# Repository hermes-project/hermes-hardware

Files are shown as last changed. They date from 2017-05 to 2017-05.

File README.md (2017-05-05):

# hermes-hardware
# Authors : François Charles, Simon Ménard, Raphaël Outhier

This repository lists all you need if you're interested in the robot hardware's architecture.

What you may find in this repository :

-the 3D models designed with SolidWorks CAD;

-the Eagle CAD PCB schematics and board layout

-the Eagle CAD libraries used

-the datasheets of electronic components

-documentation about how to drive the robot successfully (in French at the moment :p English version to come)

Enjoy your trip among these files ! :)

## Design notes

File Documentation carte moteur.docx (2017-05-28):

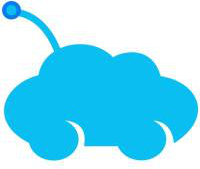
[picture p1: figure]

# Hermès ϕ – Documentation carte moteur

Auteur : François Charles-Orszag

Ce document résume les composants de la carte et ses fonctionnalités en accord avec les datasheets fournies par les constructeurs. Vous pouvez vous référer aux dites datasheets sur le site du projet Hermès, ou accéder aux liens listés dans la section Références.

## Description générale

Cette carte permet de commander un moteur à courant continu. Elle est principalement constituée de deux circuits intégrés, basés sur une structure électronique interne de pont en H. Le moteur possède trois entrées pour commander la rotation horaire, antihoraire et le freinage. Ces signaux sont compatibles avec les niveaux logiques TTL. Les différents blocs présents sur la carte sont détaillés dans la Figure 1 accompagnée de sa légende en Figure 2.

Alimentation +5V et signaux de commandes moteur

Alimentation et signaux codeur optique

Alimentation +24 V de la carte

Alimentation des moteurs

Drivers de puissance

Figure 2 : Détail des blocs

Figure 1 : Emplacement des blocs

La carte est accompagnée d’une sérigraphie (texte en blanc par-dessus le vernis vert) pour fournir une indication visuelle rapide sur les fonctions des différents contacts électriques. Ils sont détaillés dans la partie suivante Pinout et fonctionnalités.

## Pinout et fonctionnalités

Dans un premier temps, cette partie expose sous forme de tableaux les conventions utilisées pour le câblage des connecteurs. Elle montre dans un second temps comment utiliser les signaux de commande du moteur pour le contrôler. Les connectiques utilisées sont répertoriées dans la section Références, Tableau 1.

N.B. : Comprendre le mot « pin » comme une patte d’un composant, mot récurrent dans la documentation anglaise. Les secondes dénominations de la colonne fonction, comme « Vcc1 » ou « IN1 », sont liées aux notations des datasheets respectives des composants.

Connecteur d’alimentation

Numéro du pin - Couleur de câble | Fonction
1 – Rouge | +24 V / Vcc 1
2 – Noir | Masse / GND

Connecteur de moteur

Numéro du pin - Couleur de câble | Fonction
1 - Noir | Output 2
2 - Rouge | Output 1

Connecteur de codeur optique

Numéro du pin - Couleur de câble | Fonction
1 - Violet | Canal B / Hall sensor B Vout
2 - Bleu | Canal A / Hall sensor A Vout
3 - Vert | Masse / Hall sensor GND
4 - Marron | +5 V / Hall sensor Vcc

Connecteur à nappe

Numéro du pin - Couleur de câble | Fonction
1 – Marron | +5 V / Vcc 2
2 – Rouge | +5 V / Vcc 2
3 – Orange | Input 2 / IN2
4 – Jaune | Input d’activation / INH
5 – Bleu | Contrôle de courant / Sense
6 – Vert | Input 1 / IN1
7 – Violet | Masse / GND
8 – Gris | Masse / GND
9 – Blanc | Codeuse canal A / Hall sensor A Vout
10 – Noir | Codeuse canal B / Hall sensor B Vout

Commandes du moteur

Action | IN1 | IN2 | INH | Remarques
Stop 1 | H | H | H ou L | | Moteur au repos
Stop 2 | H | H | H | | Moteur en mouvement
| H | L | H
| L | H | H
Rotation horaire | H | L | L
Rotation antihoraire | L | H | L
Freinage | L | L | H ou L

H : Etat logique haut (+5V / Vcc 2) L : Etat logique bas (Masse / GND)

Chronogramme d’exemple

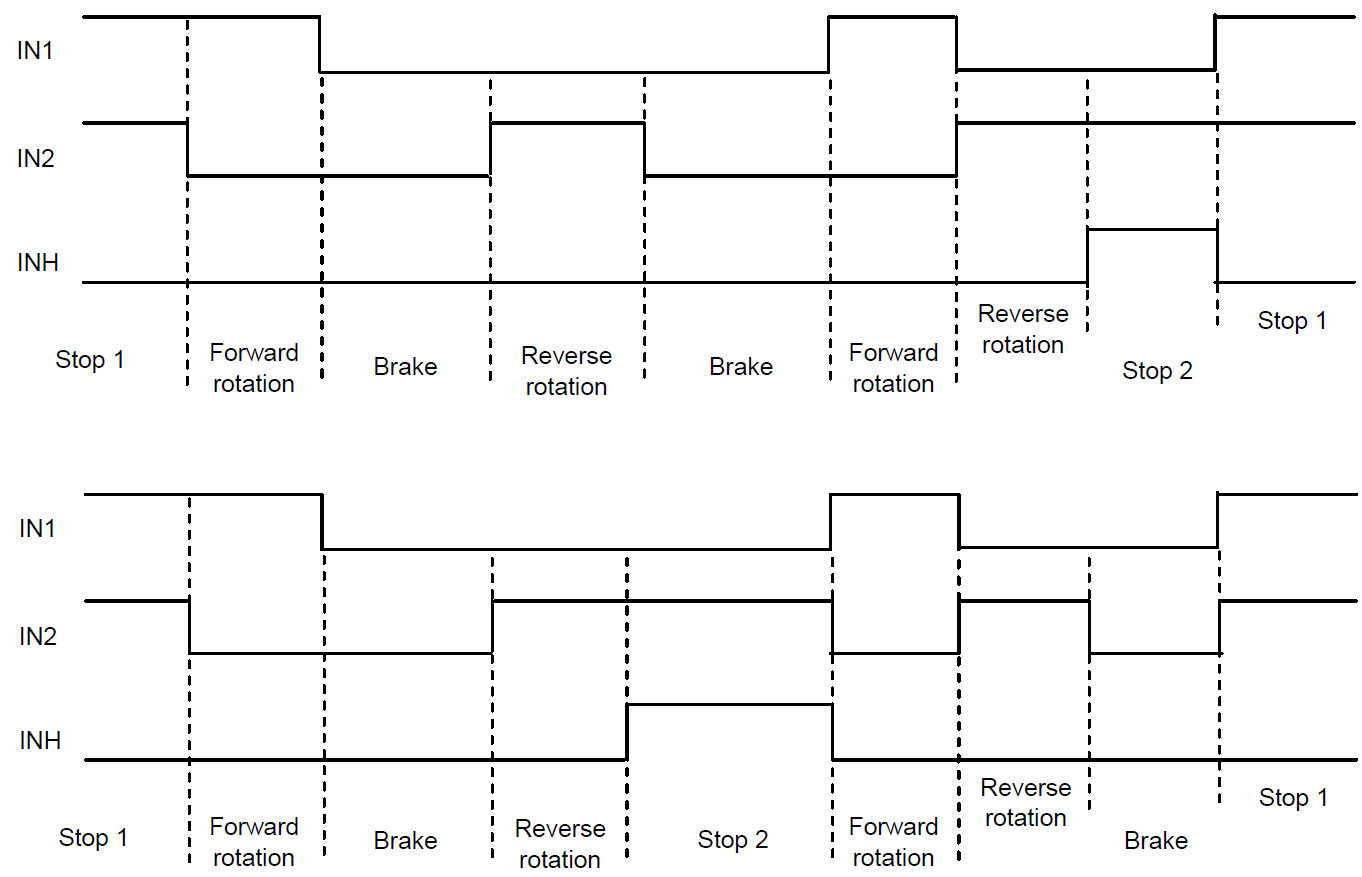
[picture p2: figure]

N.B. : La configuration IN1 = IN 2 = H et INH = L est fortement déconseillée pendant la rotation du moteur !

## Performances

Lorem ipsum.

## Précautions d’emploi et de modifications

Nous attirons l’attention de l’utilisateur dans cette partie sur les manipulations comportant des risques, aussi bien pour l’humain que pour les composants électroniques :

- Le respect des conventions de câblage est essentiel au bon fonctionnement de la carte (notamment pour le branchement de l’alimentation) car les connecteurs choisis possèdent des détrompeurs mécaniques empêchant toute erreur de polarité. Faîtes extrêmement attention si vous souhaitez changer les conventions ci-dessus, le risque étant la dégradation la carte, voire sa destruction en cas de mauvaise polarité ;
- Lors de son fonctionnement, éviter de toucher les composants de la carte, leurs boîtiers ou leurs pattes. Comme la carte fonctionne sous des courants importants quand branchés aux motoréducteurs, les composants peuvent chauffer et vous brûler. De plus, vous seriez exposé(e)s à des tensions continues d’une vingtaine de volts, issues de deux batteries au plomb. Pour éviter ces risques, la carte moteur est censée rester confinée dans son caisson de protection en utilisation ;
- En cas de dysfonctionnement, deux problèmes peuvent en être la cause. Soit les commandes des moteurs sont erronées, soit la carte ou le moteur sont endommagés. Dans le premier cas, revoyez la séquence d’ordre envoyée à la carte et vérifiez la fiabilité de l’alimentation. Dans le second cas, demandez à une personne habilitée de faire le diagnostic de la carte et de ses composants, ainsi que celui du moteur. N’essayez pas de réparer la carte si vous n’êtes pas expérimenté(e) (taper sur la carte ne la répare pas, bien que ce soit tentant) ;
- Enfin si vous voulez modifier la carte ou un de ses composants, changer la convention de câblage ou les connectiques, vous êtes priés de fournir une documentation pertinente, la présente documentation devant de facto caduque. Assurez-vous que les modifications soient adaptées à l’utilisation que vous faîtes du mobile.

## Références

Cette partie liste les liens vers les composants utilisés avec cette carte. Le tableau met en correspondance les connectiques et leurs références pour plus de clarté. En suivant ces liens, vous accéderez au site de RadioSpares, distributeur de composants électroniques.

Dénomination | Références
Alimentation | Boîtier connecteur de Molex, série SABRE (http://docs-europe.electrocomponents.com/webdocs/13c3/0900766b813c3cc1.pdf) Embase pour Circuit Imprimé de Molex, série SABRE (http://docs-europe.electrocomponents.com/webdocs/13c3/0900766b813c3b29.pdf)
Moteur | Boîtier connecteur de TE Connectivity, série MATE-N-LOK (http://docs-europe.electrocomponents.com/webdocs/03f5/0900766b803f5b91.pdf) Embase pour Circuit Imprimé de TE Connectivity, série MATE-N-LOK (http://docs-europe.electrocomponents.com/webdocs/0f93/0900766b80f93bc0.pdf)
Codeur optique | Embase pour circuit imprimé de JST, série PH (http://fr.rs-online.com/web/p/embases-de-circuit-imprime/8201434/)
Nappe | Embase pour circuit imprimé de 3M, série 303 (http://fr.rs-online.com/web/p/embases-de-circuit-imprime/8280364/) Connecteur IDC d’Amphénol, série T812 (http://fr.rs-online.com/web/p/connecteurs-idc/8323617/)

Tableau 1 : Références des connectiques

Les deux liens suivant mènent respectivement au motoréducteur et à son driver de puissance :

Motoréducteur EMG 49 de robot-electronics (http://www.robot-electronics.co.uk/htm/emg49.htm)

Driver STK681-320 de On-Semiconductor (https://www.onsemi.com/pub/Collateral/ENA0762-D.PDF)

03/05/17Documentation Carte Moteur – Hermès ϕ 2

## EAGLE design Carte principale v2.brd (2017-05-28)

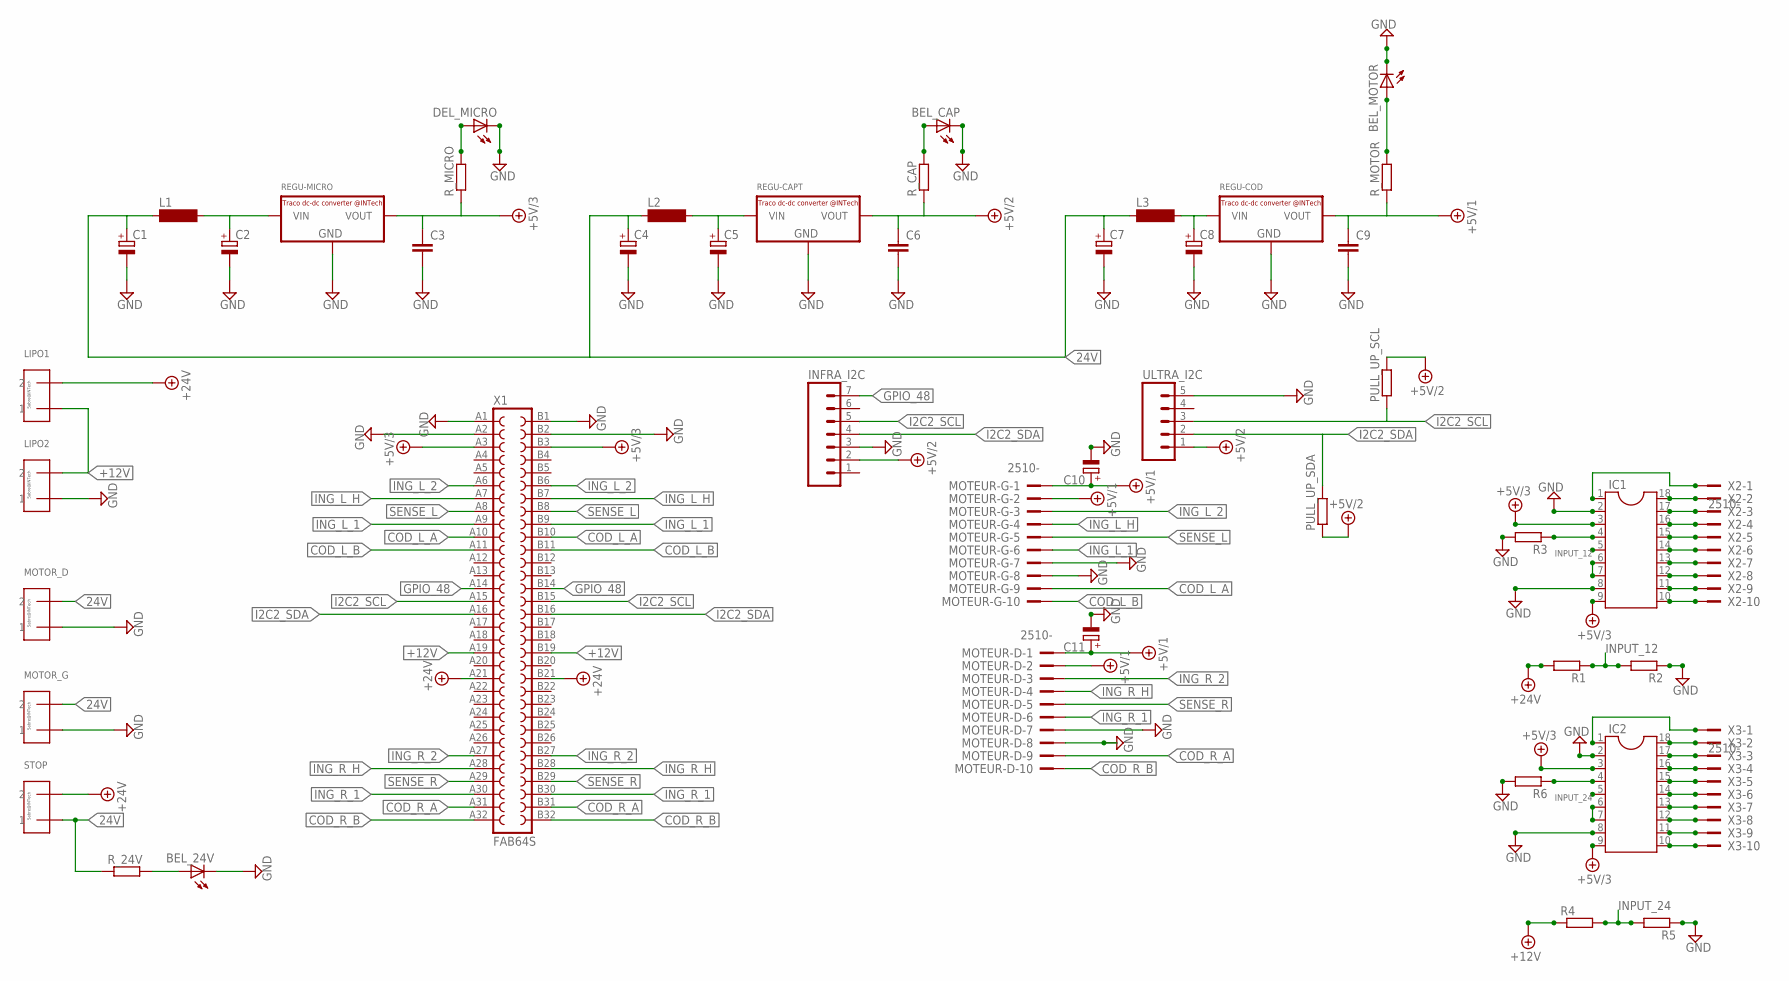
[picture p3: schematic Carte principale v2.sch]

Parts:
BEL_24V: LED5MM
BEL_CAP: LED5MM
BEL_MOTOR: LED5MM
C1, C2, C4, C5, C7, C8, C10, C11: CPOL-EUE2.5-6; E2,5-6
C3, C6: C-EU050-025X075; C050-025X075
C9: C5/3; C5B3
DEL_MICRO: LED5MM
IC1, IC2: DIL18S; SOCKET-18
INFRA_I2C: M07; 07P
L1, L2, L3: SD12-1000; SD12_1000
LIPO1, LIPO2: 43160
MOTEUR-D: 2510-; PAK100/2500-10
MOTEUR-G: 2510-; PAK100/2500-10
MOTOR_D: 43160
MOTOR_G: 43160
PULL_UP_SCL: R-EU_0204/7; 0204/7
PULL_UP_SDA: R-EU_0204/7; 0204/7
R1, R2, R3, R4, R5, R6: R-EU_0204/7; 0204/7
REGU-CAPT: R-78C-1.0_INTECH; SIP3_INTECH
REGU-COD: R-78C-1.0_INTECH; SIP3_INTECH
REGU-MICRO: R-78C-1.0_INTECH; SIP3_INTECH
R_24V: R-EU_0204/7; 0204/7
R_CAP: R-EU_0204/7; 0204/7
R_MICRO: R-EU_0204/7; 0204/7
R_MOTOR: R-EU_0204/7; 0204/7
STOP: 43160
ULTRA_I2C: M05; 05P
X1: FAB64S
X2, X3: 2510-; PAK100/2500-10

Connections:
24V: C1.+, C4.+, C7.+, L1.1, L2.1, L3.1, MOTOR_D.2_1 (2), MOTOR_D.2_2 (2), MOTOR_G.2_1 (2), MOTOR_G.2_2 (2), R_24V.1, STOP.1_1 (1), STOP.1_2 (1)
+5V/1: C9.1, C10.+, C11.+, MOTEUR-D.1, MOTEUR-D.2, MOTEUR-G.1, MOTEUR-G.2, REGU-COD.VOUT, R_MOTOR.1
+5V/2: C6.1, INFRA_I2C.2, PULL_UP_SCL.2, PULL_UP_SDA.1, REGU-CAPT.VOUT, R_CAP.1, ULTRA_I2C.1
+5V/3: C3.1, IC1.3, IC1.9, IC2.3, IC2.9, REGU-MICRO.VOUT, R_MICRO.1, X1.A3, X1.B3
+12V: LIPO1.1_1 (1), LIPO1.1_2 (1), LIPO2.2_1 (2), LIPO2.2_2 (2), R4.1, X1.A19, X1.B19
+24V: LIPO1.2_1 (2), LIPO1.2_2 (2), R1.2, STOP.2_1 (2), STOP.2_2 (2), X1.A21, X1.B21
COD_L_A: MOTEUR-G.9, X1.A10, X1.B10
COD_L_B: MOTEUR-G.10, X1.A11, X1.B11
COD_R_A: MOTEUR-D.9, X1.A31, X1.B31
COD_R_B: MOTEUR-D.10, X1.A32, X1.B32
GND: BEL_24V.K (C), BEL_CAP.K (C), BEL_MOTOR.K (C), C1.-, C2.-, C3.2, C4.-, C5.-, C6.2, C7.-, C8.-, C9.2, C10.-, C11.-, DEL_MICRO.K (C), IC1.2, IC1.8, IC2.2, IC2.8, INFRA_I2C.3, LIPO2.1_1 (1), LIPO2.1_2 (1), MOTEUR-D.7, MOTEUR-D.8, MOTEUR-G.7, MOTEUR-G.8, MOTOR_D.1_1 (1), MOTOR_D.1_2 (1), MOTOR_G.1_1 (1), MOTOR_G.1_2 (1), R2.1, R3.2, R5.1, R6.2, REGU-CAPT.GND, REGU-COD.GND, REGU-MICRO.GND, ULTRA_I2C.5, X1.A1, X1.A2, X1.B1, X1.B2
GPIO_48: INFRA_I2C.7, X1.A14, X1.B14
I2C2_SCL: INFRA_I2C.5, PULL_UP_SCL.1, ULTRA_I2C.3, X1.A15, X1.B15
I2C2_SDA: INFRA_I2C.4, PULL_UP_SDA.2, ULTRA_I2C.2, X1.A16, X1.B16
ING_L_1: MOTEUR-G.6, X1.A9, X1.B9
ING_L_2: MOTEUR-G.3, X1.A6, X1.B6
ING_L_H: MOTEUR-G.4, X1.A7, X1.B7
ING_R_1: MOTEUR-D.6, X1.A30, X1.B30
ING_R_2: MOTEUR-D.3, X1.A27, X1.B27
ING_R_H: MOTEUR-D.4, X1.A28, X1.B28
INPUT_12: IC1.5, R1.1, R2.2
INPUT_24: IC2.5, R4.2, R5.2
unnamed: DEL_MICRO.A, R_MICRO.2
unnamed: BEL_24V.A, R_24V.2
unnamed: C8.+, L3.2, REGU-COD.VIN
unnamed: C2.+, L1.2, REGU-MICRO.VIN
unnamed: C5.+, L2.2, REGU-CAPT.VIN
unnamed: BEL_CAP.A, R_CAP.2
unnamed: IC1.6, IC1.7
unnamed: IC1.12, X2.8
unnamed: IC1.13, X2.7
unnamed: BEL_MOTOR.A, R_MOTOR.2
unnamed: IC1.17, X2.3
unnamed: IC1.15, X2.5
unnamed: IC1.14, X2.6
unnamed: IC1.11, X2.9
unnamed: IC1.10, X2.10
unnamed: IC1.16, X2.4
unnamed: IC2.6, IC2.7
unnamed: IC1.18, X2.2
unnamed: IC1.1, X2.1
unnamed: IC2.10, X3.10
unnamed: IC2.11, X3.9
unnamed: IC2.12, X3.8
unnamed: IC2.13, X3.7
unnamed: IC2.14, X3.6
unnamed: IC2.15, X3.5
unnamed: IC2.16, X3.4
unnamed: IC2.17, X3.3
unnamed: IC2.18, X3.2
unnamed: IC2.1, X3.1
unnamed: IC1.4, R3.1
unnamed: IC2.4, R6.1
SENSE_L: MOTEUR-G.5, X1.A8, X1.B8
SENSE_R: MOTEUR-D.5, X1.A29, X1.B29

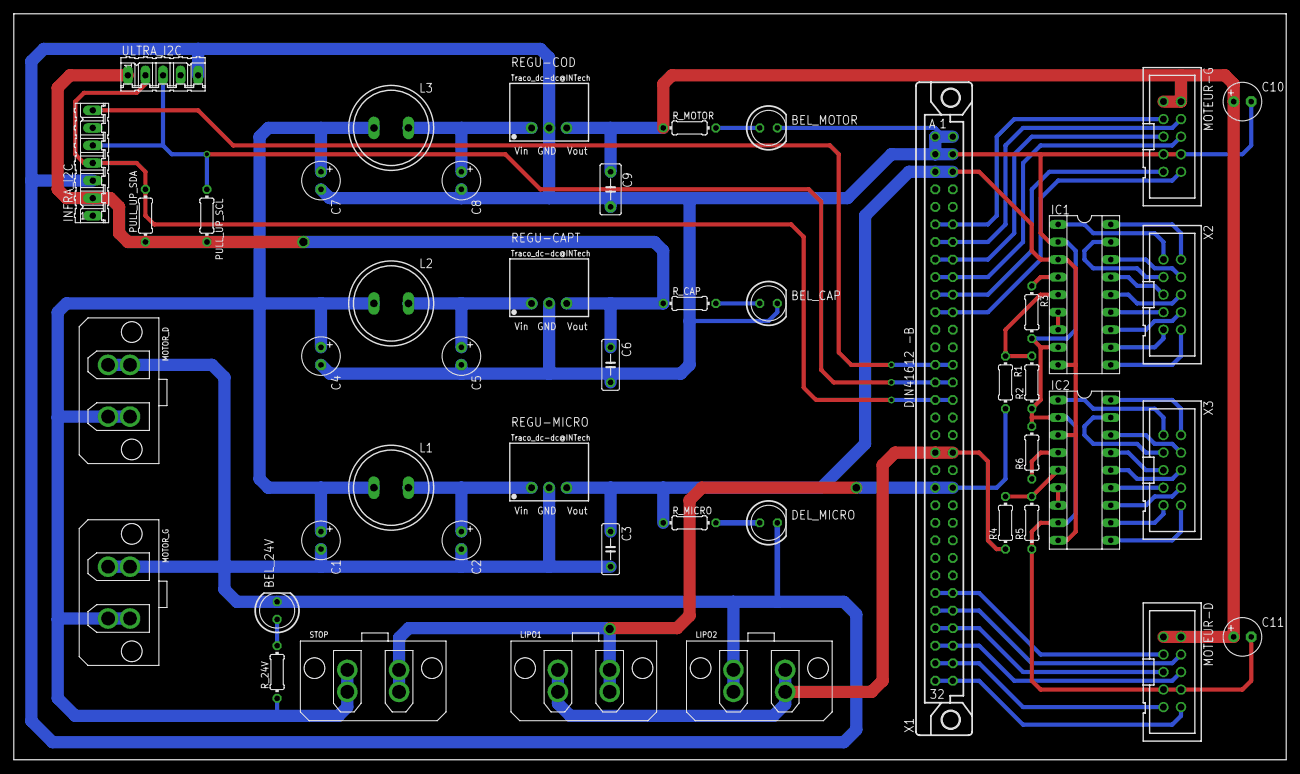
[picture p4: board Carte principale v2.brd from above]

Board: 2 copper layers, 184.1 x 108.0 mm, 47 parts (0 on the bottom side), 55 nets.

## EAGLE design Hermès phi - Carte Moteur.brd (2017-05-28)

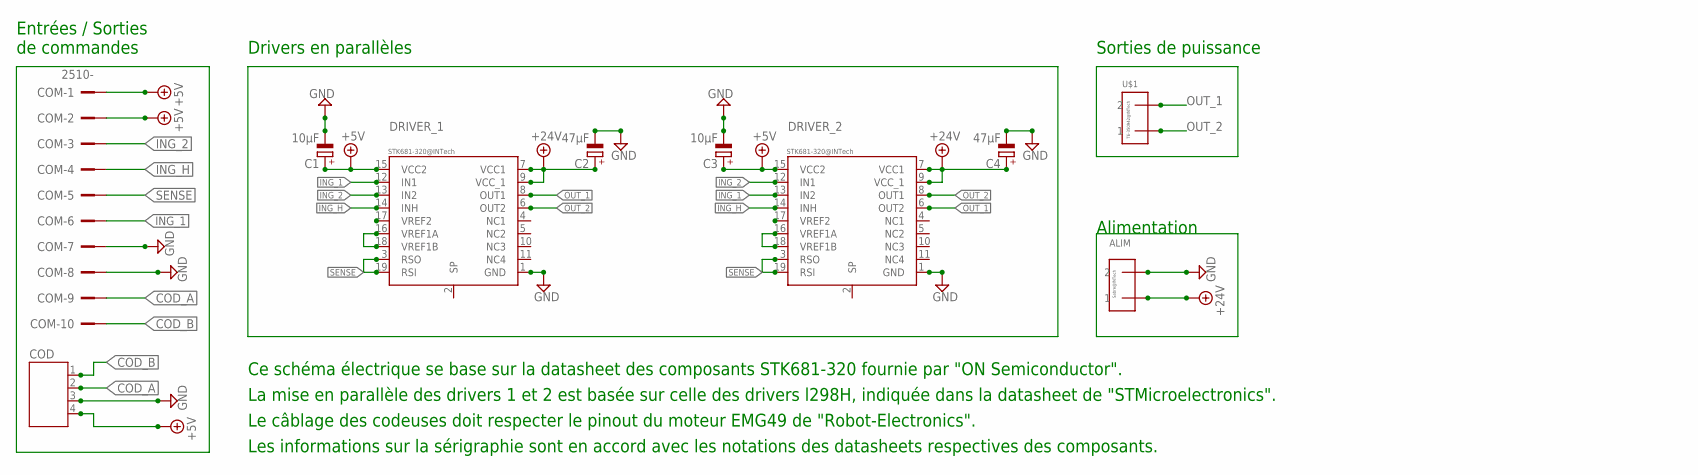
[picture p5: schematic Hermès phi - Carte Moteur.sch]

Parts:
ALIM: 43160
C1, C3: 10µF; E2,5-6E
C2, C4: 47µF; E2,5-6E
COD: JST-PH4
COM: 2510-; PAK100/2500-10
DRIVER_1, DRIVER_2: STK681-320
U$1: TE-350942; 350942

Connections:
+5V: C1.+, C3.+, COD.4, COM.1, COM.2, DRIVER_1.15 (VCC2), DRIVER_2.15 (VCC2)
+24V: ALIM.1_1 (1), ALIM.1_2 (1), C2.+, C4.+, DRIVER_1.7 (VCC1), DRIVER_1.9 (VCC_1), DRIVER_2.7 (VCC1), DRIVER_2.9 (VCC_1)
COD_A: COD.2, COM.9
COD_B: COD.1, COM.10
GND: ALIM.2_1 (2), ALIM.2_2 (2), C1.-, C2.-, C3.-, C4.-, COD.3, COM.7, COM.8, DRIVER_1.1 (GND), DRIVER_2.1 (GND)
ING_1: COM.6, DRIVER_1.12 (IN1), DRIVER_2.13 (IN2)
ING_2: COM.3, DRIVER_1.13 (IN2), DRIVER_2.12 (IN1)
ING_H: COM.4, DRIVER_1.14 (INH), DRIVER_2.14 (INH)
unnamed: DRIVER_1.16 (VREF1A), DRIVER_1.18 (VREF1B)
unnamed: DRIVER_2.16 (VREF1A), DRIVER_2.18 (VREF1B)
OUT_1: DRIVER_1.8 (OUT1), DRIVER_2.6 (OUT2), U$1.2
OUT_2: DRIVER_1.6 (OUT2), DRIVER_2.8 (OUT1), U$1.1
SENSE: COM.5, DRIVER_1.3 (RSO), DRIVER_1.19 (RSI), DRIVER_2.3 (RSO), DRIVER_2.19 (RSI)

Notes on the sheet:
Drivers en parallèles
Entrées / Sorties de commandes
Alimentation
Sorties de puissance
Ce schéma électrique se base sur la datasheet des composants STK681-320 fournie par "ON Semiconductor".
La mise en parallèle des drivers 1 et 2 est basée sur celle des drivers l298H, indiquée dans la datasheet de "STMicroelectronics".
Le câblage des codeuses doit respecter le pinout du moteur EMG49 de "Robot-Electronics".
Les informations sur la sérigraphie sont en accord avec les notations des datasheets respectives des composants.

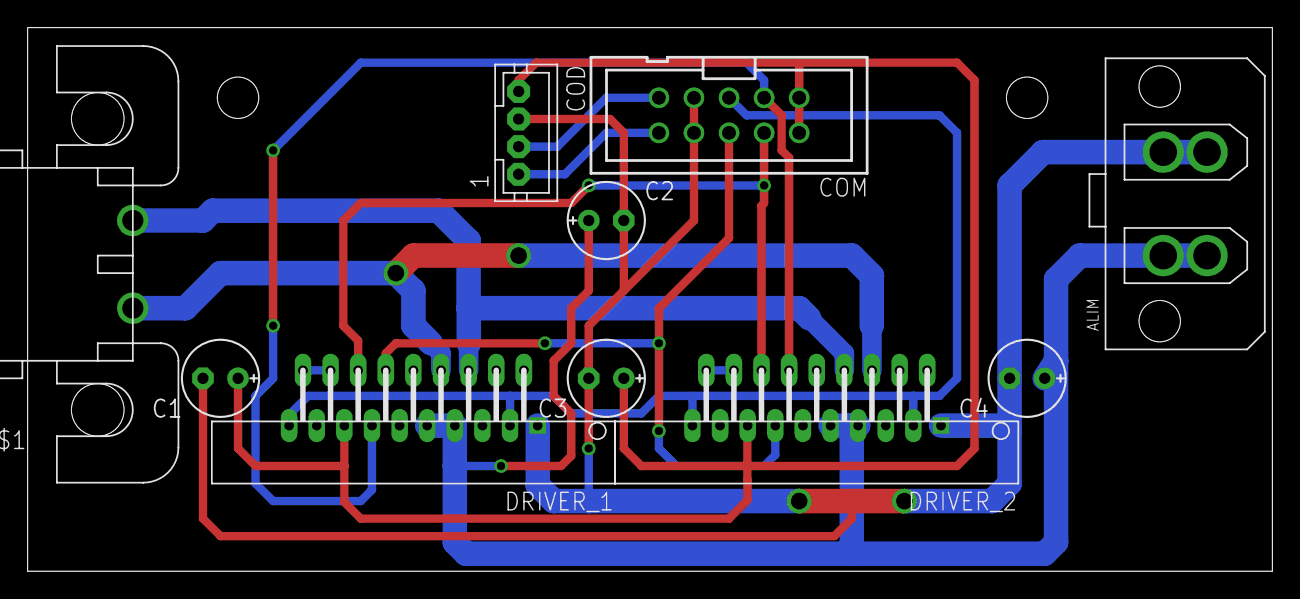
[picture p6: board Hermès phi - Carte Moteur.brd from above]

Board: 2 copper layers, 90.2 x 39.4 mm, 10 parts (0 on the bottom side), 13 nets.

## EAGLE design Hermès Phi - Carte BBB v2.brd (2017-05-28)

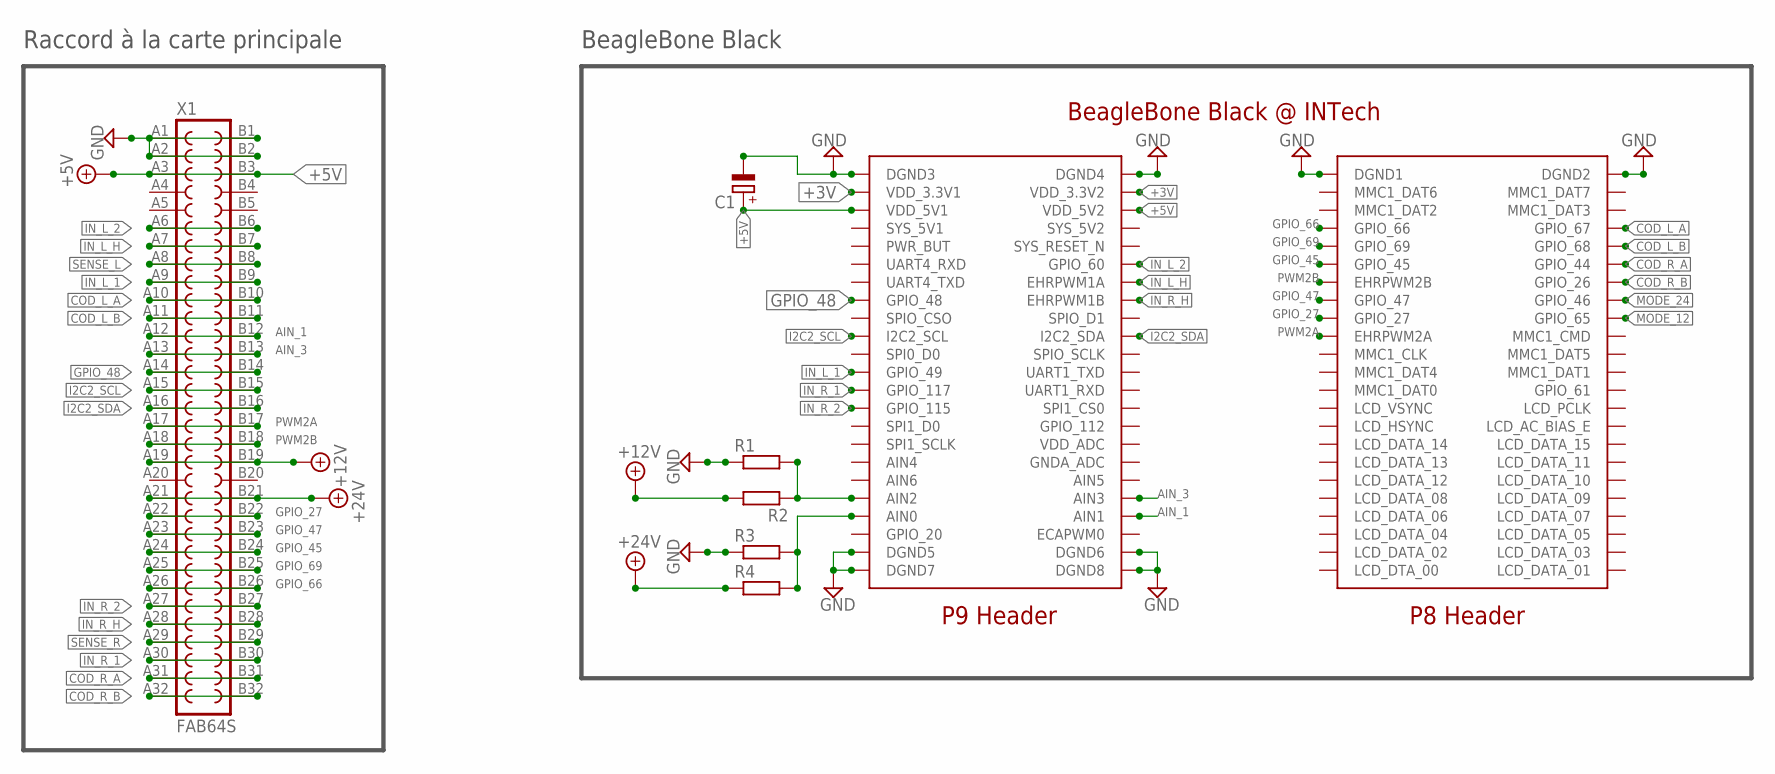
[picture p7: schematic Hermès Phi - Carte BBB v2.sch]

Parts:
C1: CPOL-EUE2.5-5; E2,5-5
R1, R2, R3, R4: R-EU_0204/7; 0204/7
U$1: BBB
X1: FAB64S

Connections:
+3V: U$1.VDD_3.3V1, U$1.VDD_3.3V2
+5V: C1.+, U$1.VDD_5V1, U$1.VDD_5V2, X1.A3, X1.B3
+12V: R2.2, X1.A19, X1.B19
+24V: R4.1, X1.A21, X1.B21
AIN_1: U$1.AIN1, X1.A12, X1.B12
AIN_3: U$1.AIN3, X1.A13, X1.B13
COD_L_A: U$1.GPIO_67, X1.A10, X1.B10
COD_L_B: U$1.GPIO_68, X1.A11, X1.B11
COD_R_A: U$1.GPIO_44, X1.A31, X1.B31
COD_R_B: U$1.GPIO_26, X1.A32, X1.B32
GND: C1.-, R1.1, R3.1, U$1.DGND1, U$1.DGND2, U$1.DGND3, U$1.DGND4, U$1.DGND5, U$1.DGND6, U$1.DGND7, U$1.DGND8, X1.A1, X1.A2, X1.B1, X1.B2
GPIO_27: U$1.GPIO_27, X1.A22, X1.B22
GPIO_45: U$1.GPIO_45, X1.A24, X1.B24
GPIO_47: U$1.GPIO_47, X1.A23, X1.B23
GPIO_48: U$1.GPIO_48, X1.A14, X1.B14
GPIO_66: U$1.GPIO_66, X1.A26, X1.B26
GPIO_69: U$1.GPIO_69, X1.A25, X1.B25
I2C2_SCL: U$1.I2C2_SCL, X1.A15, X1.B15
I2C2_SDA: U$1.I2C_SDA (I2C2_SDA), X1.A16, X1.B16
IN_L_1: U$1.GPIO_49, X1.A9, X1.B9
IN_L_2: U$1.GPIO_60, X1.A6, X1.B6
IN_L_H: U$1.EHRPWM1A, X1.A7, X1.B7
IN_R_1: U$1.GPIO_117, X1.A30, X1.B30
IN_R_2: U$1.GPIO_115, X1.A27, X1.B27
IN_R_H: U$1.EHRPWM1B, X1.A28, X1.B28
MODE_12: U$1.GPIO_65
MODE_24: U$1.GPIO_46
unnamed: R3.2, R4.2, U$1.AIN0
unnamed: R1.2, R2.1, U$1.AIN2
PWM2A: U$1.EHRPWM2A, X1.A17, X1.B17
PWM2B: U$1.EHRPWMB2 (EHRPWM2B), X1.A18, X1.B18
SENSE_L: X1.A8, X1.B8
SENSE_R: X1.A29, X1.B29

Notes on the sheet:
Raccord à la carte principale
BeagleBone Black

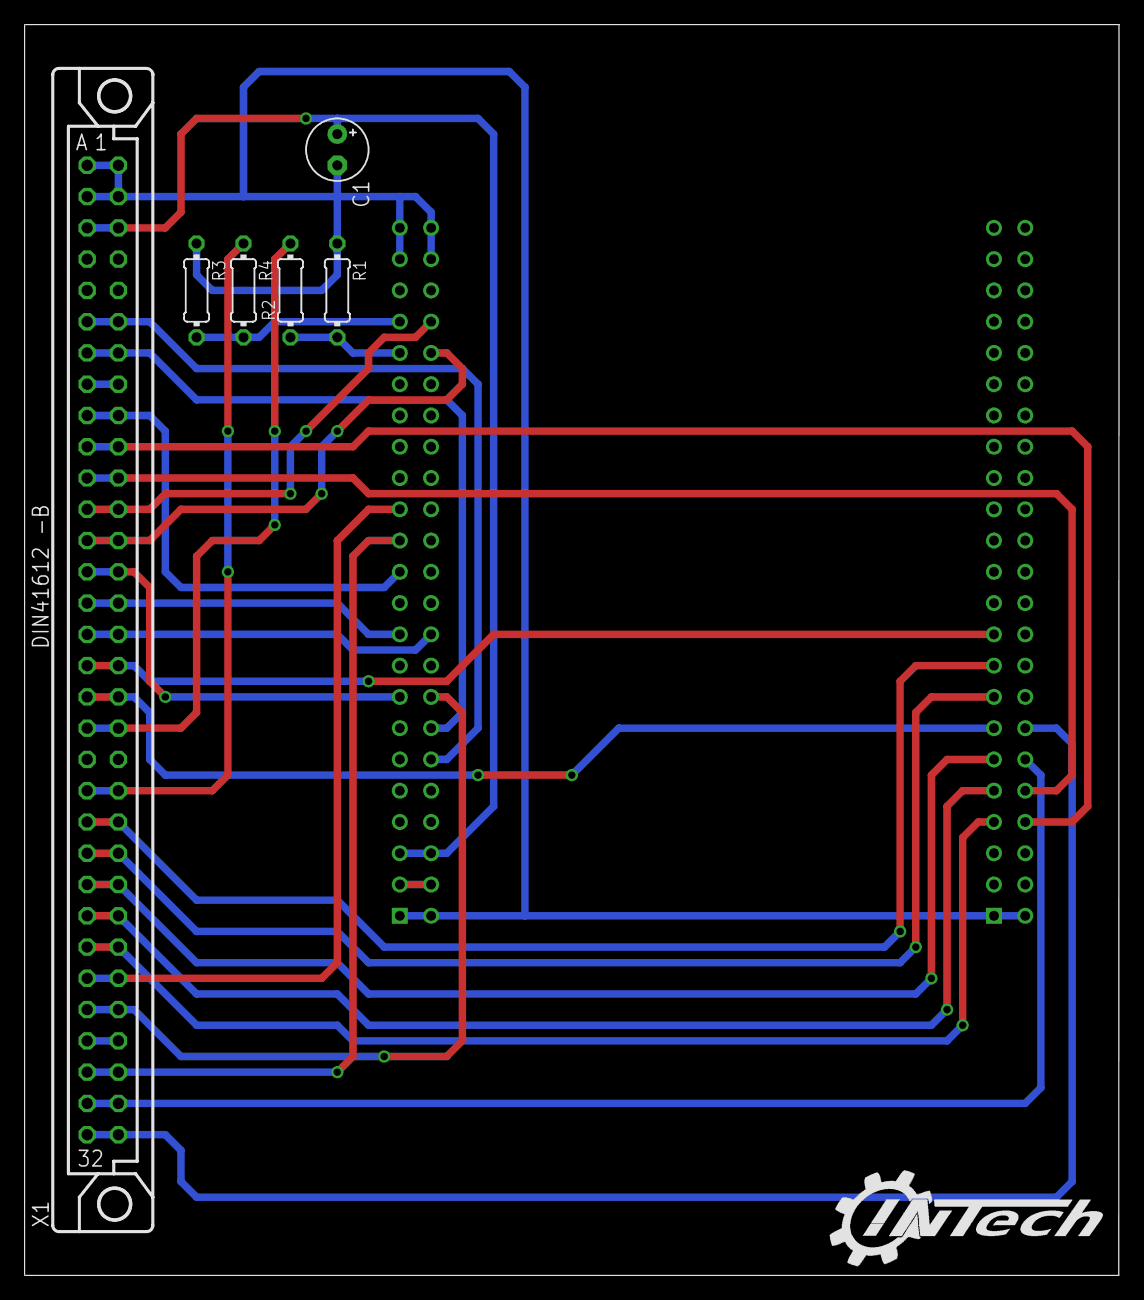
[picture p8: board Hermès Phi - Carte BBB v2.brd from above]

Board: 2 copper layers, 88.9 x 101.6 mm, 7 parts (1 on the bottom side), 31 nets.
